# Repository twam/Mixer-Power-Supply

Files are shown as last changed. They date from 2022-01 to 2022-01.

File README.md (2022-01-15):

Mixer-Power-Supply
===

This repository is part of the USB audio mixer project described on https://www.twam.info/general/building-a-custom-usb-audio-mixer.

## License

[][cc-by-sa]

This work is licensed under a [Creative Commons Attribution-NonCommercial-ShareAlike 4.0 International License][cc-by-sa].

[][cc-by-sa]

[cc-by-sa]: http://creativecommons.org/licenses/by-nc-sa/4.0/
[cc-by-sa-image]: https://licensebuttons.net/l/by-nc-sa/4.0/88x31.png
[cc-by-sa-shield]: https://img.shields.io/badge/License-CC%20BY--NC--SA%204.0-lightgrey.svg

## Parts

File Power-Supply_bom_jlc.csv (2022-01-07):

Comment | Designator | Footprint | LCSC Part #
10u/50V | C1,C2,C3,C5,C6,C7 | C_1206_3216Metric | C13585
100nF | C4,C19,C8,C20,C21,C22,C28,C29 | C_0805_2012Metric | C49678
220u/35V | C14,C15,C16,C17 | CP_Radial_D8.0mm_P3.50mm | C201212
4u7 | C23 | C_0805_2012Metric | C1779
10p | C24 | C_0805_2012Metric | C1785
10u | C25,C26,C34 | C_0805_2012Metric | C15850
1u | C27 | C_0805_2012Metric | C28323
100nF | C30,C31,C32,C33 | C_0603_1608Metric | C14663
LL4148 | D1,D2,D3,D12 | D_MiniMELF | C9808
green | D4 | LED_0805_2012Metric | C2297
red | D5,D6,D7,D8,D9,D10,D11 | LED_0805_2012Metric | C84256
2A | F1,F2,F3 | Fuse_0603_1608Metric_Pad1.05x0.95mm_HandSolder | C187605
600R/100M | L2,L3,L5 | L_0805_2012Metric | C1017
2u2 | L4 | L_0805_2012Metric | C216156
AO3400A | Q1,Q2,Q3,Q4 | TSOT-23 | C20917
0R | R1,R15,R7,R22,R26,R31,R34 | R_0805_2012Metric | C17477
2k | R2 | R_0805_2012Metric | C17604
22k | R3 | R_0805_2012Metric | C17560
270k | R4,R17 | R_0805_2012Metric | C17589
3k3 | R5 | R_0805_2012Metric | C26010
11k | R6,R11,R18,R25,R27 | R_0805_2012Metric | C17429
39k | R9,R8,R12 | R_0805_2012Metric | C25826
4k7 | R10 | R_0805_2012Metric | C17673
68k | R13 | R_0805_2012Metric | C17801
470R | R14 | R_0805_2012Metric | C17709
10k | R16,R23,R28,R32,R33,R35,R36,R38 | R_0805_2012Metric | C17414
15k | R24 | R_0805_2012Metric | C17475
0R01 | R29 | R_1206_3216Metric | C308574
249k | R30 | R_0805_2012Metric | C25825
81R | R39 | R_0805_2012Metric | C17819
RESET | SW1 | SW_SPST_B3U-1000P | C231329
TLC5916IDR | U4 | SOIC-16_3.9x9.9mm_P1.27mm | C90107
NE5532 | U7 | SOIC-8_3.9x4.9mm_P1.27mm | C7426
TLV62569DBV | U8 | SOT-23-5 | C141836
INA138 | U9 | SOT-23-5 | C47914
MCP6002-xSN | U10 | SOIC-8_3.9x4.9mm_P1.27mm | C7377

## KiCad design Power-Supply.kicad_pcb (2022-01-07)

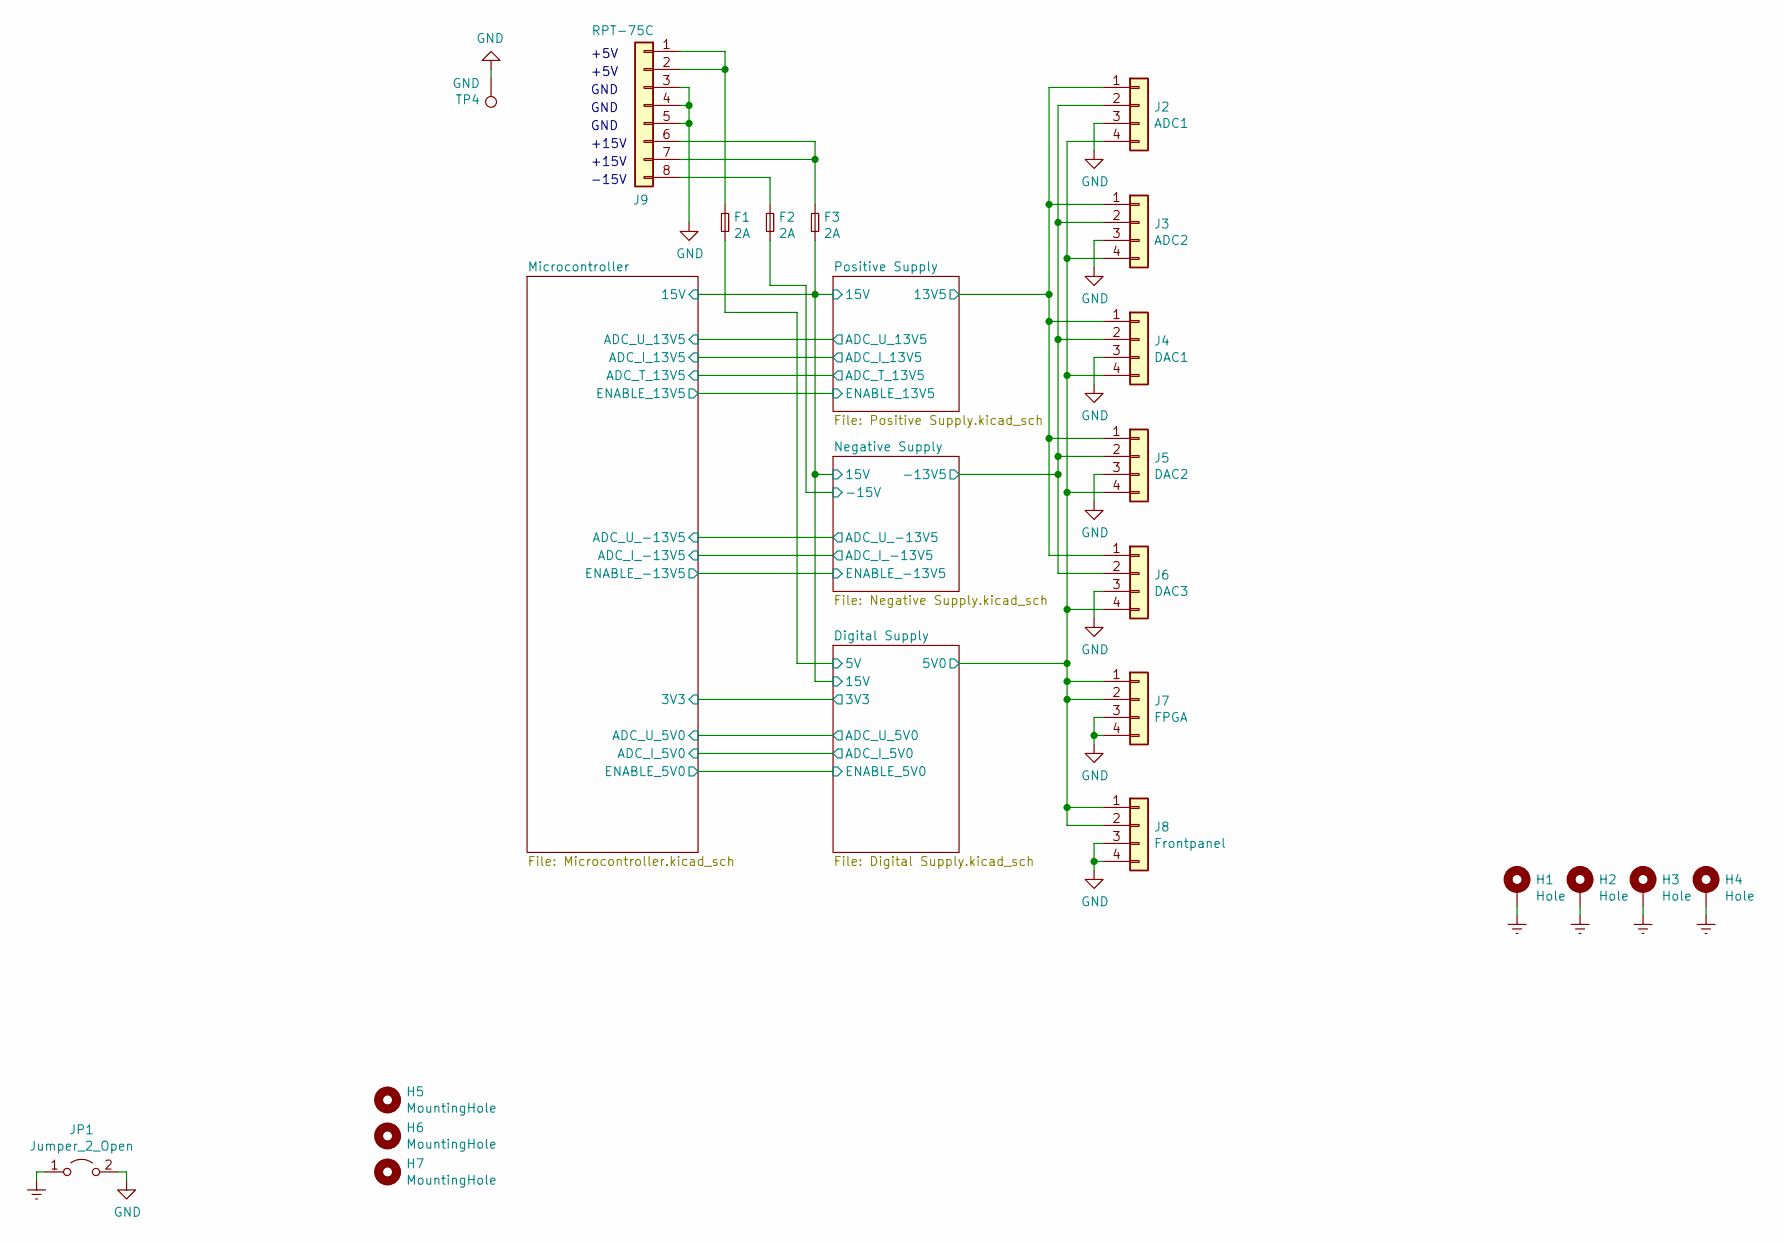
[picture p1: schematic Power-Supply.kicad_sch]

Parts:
F1, F2, F3: 2A; Fuse_0603_1608Metric_Pad1.05x0.95mm_HandSolder; LCSC C187605
H1, H2, H3, H4: Hole; MountingHole_3.2mm_M3_DIN965_Pad
H5, H6, H7: MountingHole; MountingHole_JLCPCB
J2: ADC1; JST_VH_B4P-VH_1x04_P3.96mm_Vertical
J3: ADC2; JST_VH_B4P-VH_1x04_P3.96mm_Vertical
J4: DAC1; JST_VH_B4P-VH_1x04_P3.96mm_Vertical
J5: DAC2; JST_VH_B4P-VH_1x04_P3.96mm_Vertical
J6: DAC3; JST_VH_B4P-VH_1x04_P3.96mm_Vertical
J7: FPGA; JST_VH_B4P-VH_1x04_P3.96mm_Vertical
J8: Frontpanel; JST_VH_B4P-VH_1x04_P3.96mm_Vertical
J9: RPT-75C; JST_VH_B8P-VH_1x08_P3.96mm_Vertical
JP1: Jumper_2_Open; SolderJumper-2_P1.3mm_Open_RoundedPad1.0x1.5mm
TP4: GND; TestPoint_Pad_D2.0mm

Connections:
/Digital Supply/5V: F1.1; also elsewhere on the board
/Digital Supply/5V0: J2.4, J3.4, J4.4, J5.4, J6.4, J7.1, J7.2, J8.1, J8.2; also elsewhere on the board
/Digital Supply/15V: F3.1; also elsewhere on the board
/Negative Supply/-13V5: J2.2, J3.2, J4.2, J5.2, J6.2; also elsewhere on the board
/Negative Supply/-15V: F2.1; also elsewhere on the board
/Positive Supply/13V5: J2.1, J3.1, J4.1, J5.1, J6.1; also elsewhere on the board
Earth: H1.1, H2.1, H3.1, H4.1, JP1.1 (A)
GND: J2.3, J3.3, J4.3, J5.3, J6.3, J7.3, J7.4, J8.3, J8.4, J9.3, J9.4, J9.5, JP1.2 (B), TP4.1; also elsewhere on the board
unnamed: F1.2, J9.1, J9.2
unnamed: F2.2, J9.8
unnamed: F3.2, J9.6, J9.7

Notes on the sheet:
+5V
GND
-15V
+15V

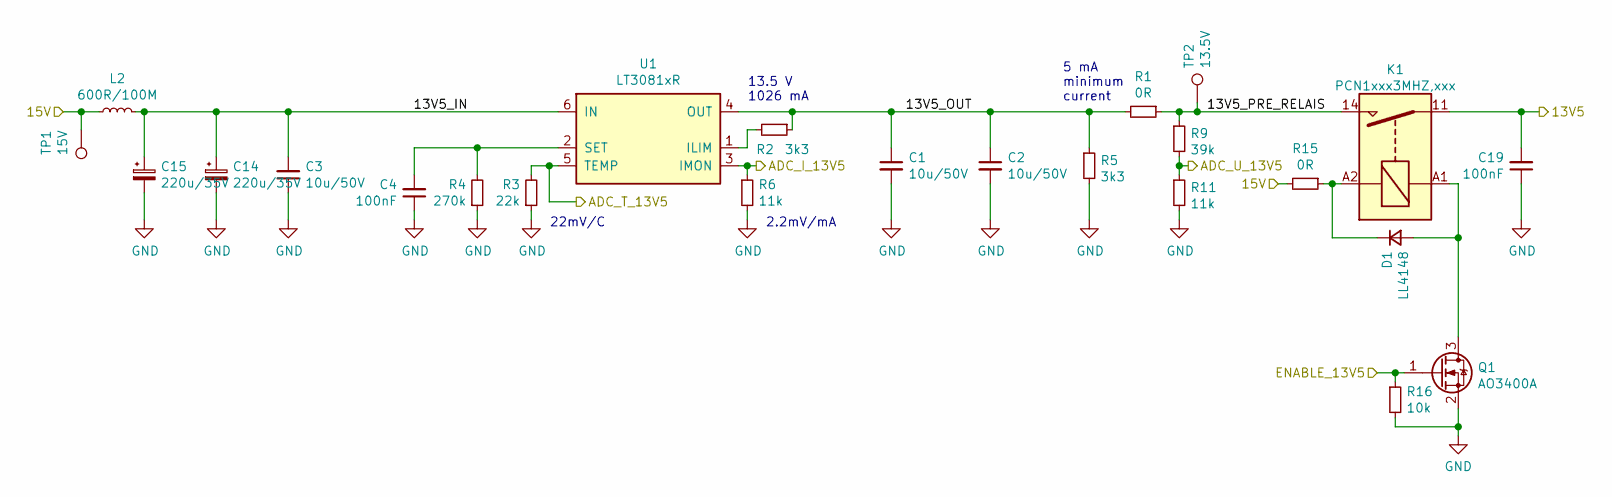
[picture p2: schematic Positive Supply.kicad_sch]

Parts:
C1, C2, C3: 10u/50V; C_1206_3216Metric; LCSC C13585
C4, C19: 100nF; C_0805_2012Metric; LCSC C49678
C14, C15: 220u/35V; CP_Radial_D8.0mm_P3.50mm; LCSC C201212
D1: LL4148; D_MiniMELF; LCSC C9808
K1: PCN1xxx3MHZ,xxx
L2: 600R/100M; L_0805_2012Metric; LCSC C1017
Q1: AO3400A; TSOT-23; LCSC C20917
R1, R15: 0R; R_0805_2012Metric; LCSC C17477
R2, R5: 3k3; R_0805_2012Metric; LCSC C26010
R3: 22k; R_0805_2012Metric; LCSC C17560
R4: 270k; R_0805_2012Metric; LCSC C17589
R6, R11: 11k; R_0805_2012Metric; LCSC C17429
R9: 39k; R_0805_2012Metric; LCSC C25826
R16: 10k; R_0805_2012Metric; LCSC C17414
TP1: 15V; TestPoint_Pad_D2.0mm
TP2: 13.5V; TestPoint_Pad_D2.0mm
U1: LT3081xR; TO-220-7_P2.54x3.8mm_StaggerOdd_Lead5.85mm_TabDown

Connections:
/Digital Supply/15V: L2.1, R15.2, TP1.1; also elsewhere on the board
/Microcontroller/ADC_I_13V5: R6.1, U1.3 (IMON); also elsewhere on the board
/Microcontroller/ADC_T_13V5: R3.2, U1.5 (TEMP); also elsewhere on the board
/Microcontroller/ADC_U_13V5: R9.2, R11.1; also elsewhere on the board
/Microcontroller/ENABLE_13V5: Q1.1 (G), R16.1; also elsewhere on the board
/Positive Supply/13V5: C19.2, K1.11; also elsewhere on the board
/Positive Supply/13V5_IN: C3.2, C14.1, C15.1, L2.2, U1.6 (IN)
/Positive Supply/13V5_OUT: C1.1, C2.1, R1.2, R2.1, R5.1, U1.4 (OUT)
/Positive Supply/13V5_PRE_RELAIS: K1.14, R1.1, R9.1, TP2.1
GND: C1.2, C2.2, C3.1, C4.1, C14.2, C15.2, C19.1, Q1.2 (S), R3.1, R4.1, R5.2, R6.2, R11.2, R16.2; also elsewhere on the board
unnamed: C4.2, R4.2, U1.2 (SET)
unnamed: D1.1 (K), K1.A2, R15.1
unnamed: D1.2 (A), K1.A1, Q1.3 (D)
unnamed: R2.2, U1.1 (ILIM)

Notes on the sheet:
2.2mV/mA
5 mA minimum current
22mV/C
13.5 V 1026 mA

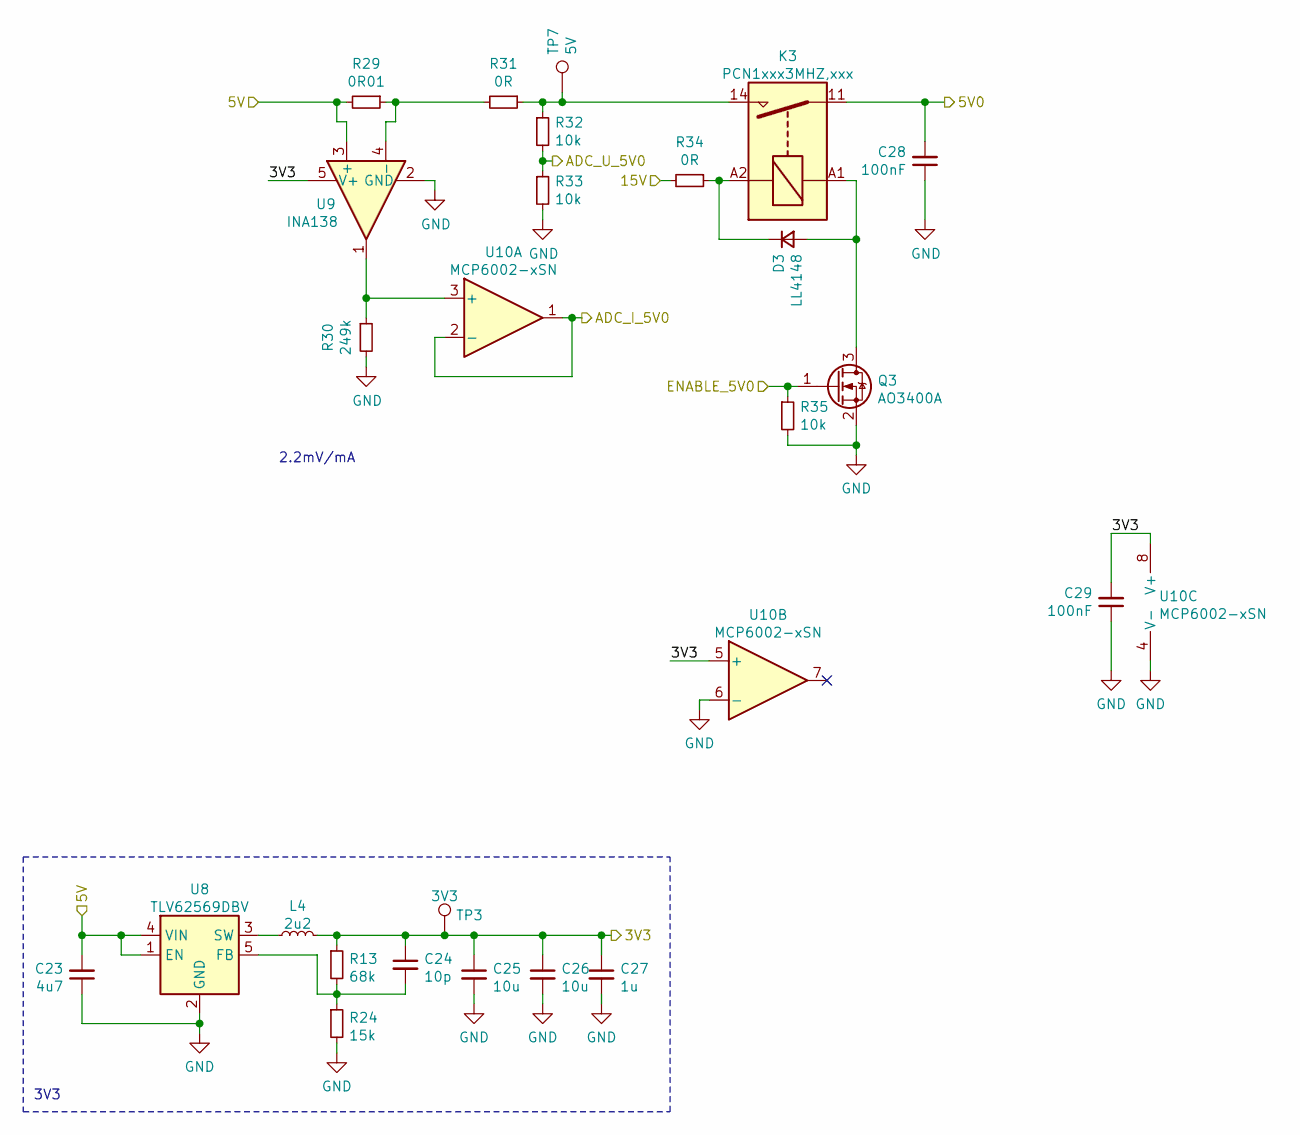
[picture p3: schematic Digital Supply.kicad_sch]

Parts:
C23: 4u7; C_0805_2012Metric; LCSC C1779
C24: 10p; C_0805_2012Metric; LCSC C1785
C25, C26: 10u; C_0805_2012Metric; LCSC C15850
C27: 1u; C_0805_2012Metric; LCSC C28323
C28, C29: 100nF; C_0805_2012Metric; LCSC C49678
D3: LL4148; D_MiniMELF; LCSC C9808
K3: PCN1xxx3MHZ,xxx
L4: 2u2; L_0805_2012Metric; LCSC C216156
Q3: AO3400A; TSOT-23; LCSC C20917
R13: 68k; R_0805_2012Metric; LCSC C17801
R24: 15k; R_0805_2012Metric; LCSC C17475
R29: 0R01; R_1206_3216Metric; LCSC C308574
R30: 249k; R_0805_2012Metric; LCSC C25825
R31, R34: 0R; R_0805_2012Metric; LCSC C17477
R32, R33, R35: 10k; R_0805_2012Metric; LCSC C17414
TP3: 3V3; TestPoint_Pad_D1.5mm
TP7: 5V; TestPoint_Pad_D2.0mm
U8: TLV62569DBV; SOT-23-5; LCSC C141836
U9: INA138; SOT-23-5; LCSC C47914
U10: MCP6002-xSN; SOIC-8_3.9x4.9mm_P1.27mm

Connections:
/Digital Supply/3V3: C24.1, C25.1, C26.1, C27.1, C29.2, L4.2, R13.1, TP3.1, U9.5 (V+), U10.5 (+), U10.8 (V+); also elsewhere on the board
/Digital Supply/5V: C23.2, R29.2, U8.1 (EN), U8.4 (VIN), U9.3 (+); also elsewhere on the board
/Digital Supply/5V0: C28.2, K3.11; also elsewhere on the board
/Digital Supply/15V: R34.2; also elsewhere on the board
/Digital Supply/ADC_I_5V0: U10.1, U10.2 (-); also elsewhere on the board
/Digital Supply/ADC_U_5V0: R32.2, R33.1; also elsewhere on the board
/Digital Supply/ENABLE_5V0: Q3.1 (G), R35.1; also elsewhere on the board
GND: C23.1, C25.2, C26.2, C27.2, C28.1, C29.1, Q3.2 (S), R24.2, R30.2, R33.2, R35.2, U8.2 (GND), U9.2 (GND), U10.4 (V-), U10.6 (-); also elsewhere on the board
unnamed: C24.2, R13.2, R24.1, U8.5 (FB)
unnamed: D3.1 (K), K3.A2, R34.1
unnamed: D3.2 (A), K3.A1, Q3.3 (D)
unnamed: K3.14, R31.1, R32.1, TP7.1
unnamed: L4.1, U8.3 (SW)
unnamed: R29.1, R31.2, U9.4 (-)
unnamed: R30.1, U9.1, U10.3 (+)

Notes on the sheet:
2.2mV/mA
3V3

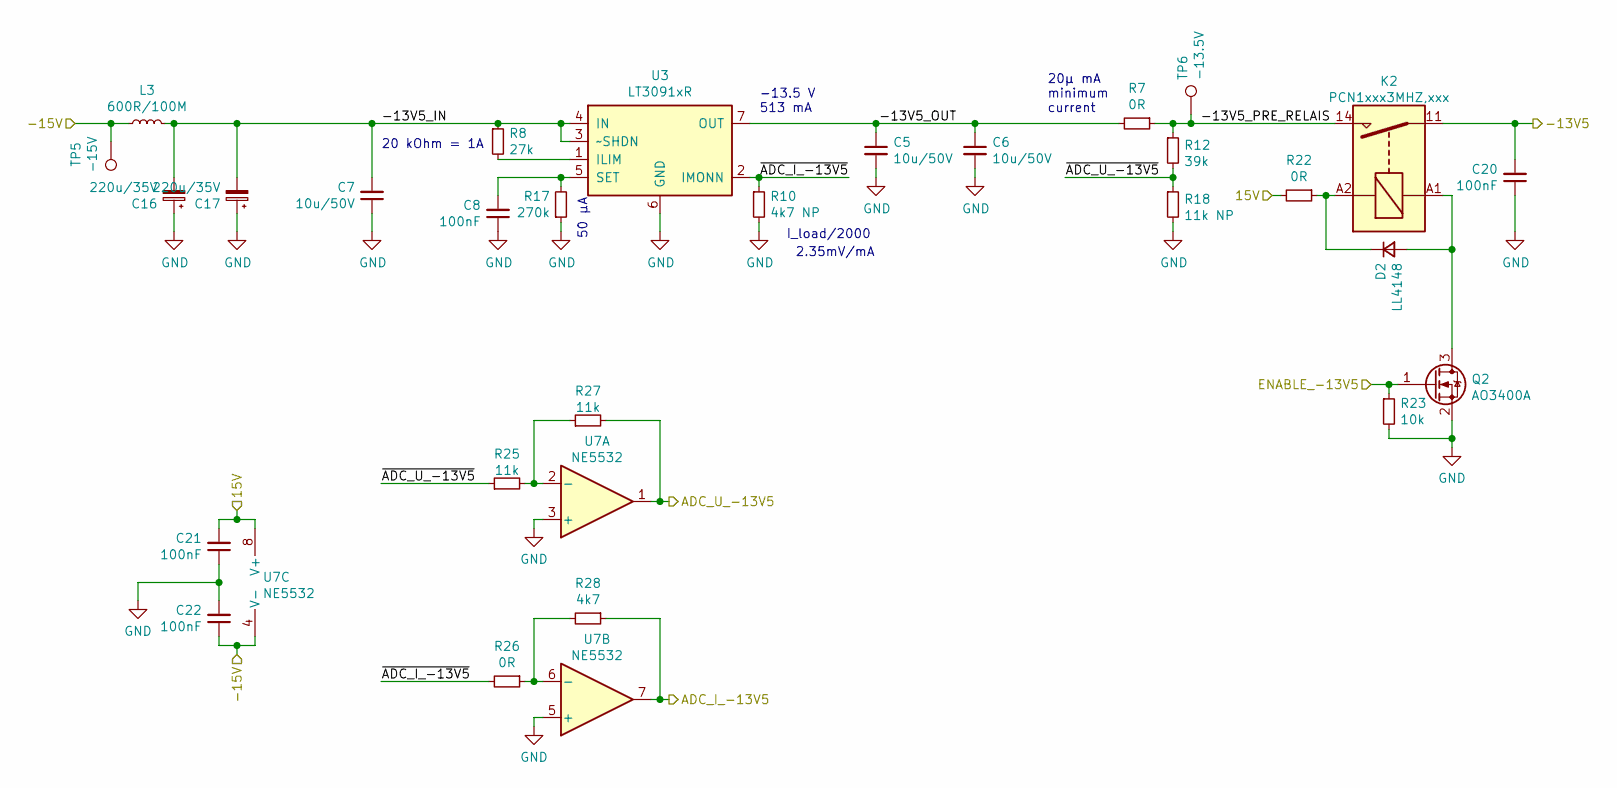
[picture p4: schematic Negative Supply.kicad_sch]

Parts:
C5, C6, C7: 10u/50V; C_1206_3216Metric; LCSC C13585
C8, C20, C21, C22: 100nF; C_0805_2012Metric; LCSC C49678
C16, C17: 220u/35V; CP_Radial_D8.0mm_P3.50mm; LCSC C201212
D2: LL4148; D_MiniMELF; LCSC C9808
K2: PCN1xxx3MHZ,xxx
L3: 600R/100M; L_0805_2012Metric; LCSC C1017
Q2: AO3400A; TSOT-23; LCSC C20917
R7, R22, R26: 0R; R_0805_2012Metric; LCSC C17477
R8: 27k; R_0805_2012Metric; LCSC C26010
R10: 4k7 NP; R_0805_2012Metric; LCSC C17673
R12: 39k; R_0805_2012Metric; LCSC C25826
R17: 270k; R_0805_2012Metric; LCSC C17589
R18: 11k NP; R_0805_2012Metric
R23: 10k; R_0805_2012Metric; LCSC C17414
R25, R27: 11k; R_0805_2012Metric; LCSC C17429
R28: 4k7; R_0805_2012Metric; LCSC C17673
TP5: -15V; TestPoint_Pad_D2.0mm
TP6: -13.5V; TestPoint_Pad_D2.0mm
U3: LT3091xR; TO-220-7_P2.54x3.8mm_StaggerOdd_Lead5.85mm_TabDown
U7: NE5532; SOIC-8_3.9x4.9mm_P1.27mm

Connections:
/Digital Supply/15V: C21.2, R22.2, U7.8 (V+); also elsewhere on the board
/Microcontroller/ADC_I_-13V5: R28.1, U7.7; also elsewhere on the board
/Microcontroller/ADC_U_-13V5: R27.2, U7.1; also elsewhere on the board
/Microcontroller/ENABLE_-13V5: Q2.1 (G), R23.1; also elsewhere on the board
/Negative Supply/-13V5: C20.2, K2.11; also elsewhere on the board
/Negative Supply/-13V5_IN: C7.2, C16.2, C17.2, L3.2, R8.1, U3.3 (~SHDN), U3.4 (IN)
/Negative Supply/-13V5_OUT: C5.1, C6.1, R7.2, U3.7 (OUT)
/Negative Supply/-13V5_PRE_RELAIS: K2.14, R7.1, R12.1, TP6.1
/Negative Supply/-15V: C22.1, L3.1, TP5.1, U7.4 (V-); also elsewhere on the board
/Negative Supply/~ADC_I_-13V5: R10.1, R26.2, U3.2 (IMONN)
/Negative Supply/~ADC_U_-13V5: R12.2, R18.1, R25.1
GND: C5.2, C6.2, C7.1, C8.1, C16.1, C17.1, C20.1, C21.1, C22.2, Q2.2 (S), R10.2, R17.1, R18.2, R23.2, U3.6 (GND), U7.3 (+), U7.5 (+); also elsewhere on the board
unnamed: C8.2, R17.2, U3.5 (SET)
unnamed: D2.1 (K), K2.A2, R22.1
unnamed: D2.2 (A), K2.A1, Q2.3 (D)
unnamed: R8.2, U3.1 (ILIM)
unnamed: R25.2, R27.1, U7.2 (-)
unnamed: R26.1, R28.2, U7.6 (-)

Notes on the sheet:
20µ mA minimum current
20 kOhm = 1A
I_load/2000
50 µA
2.35mV/mA
-13.5 V 513 mA

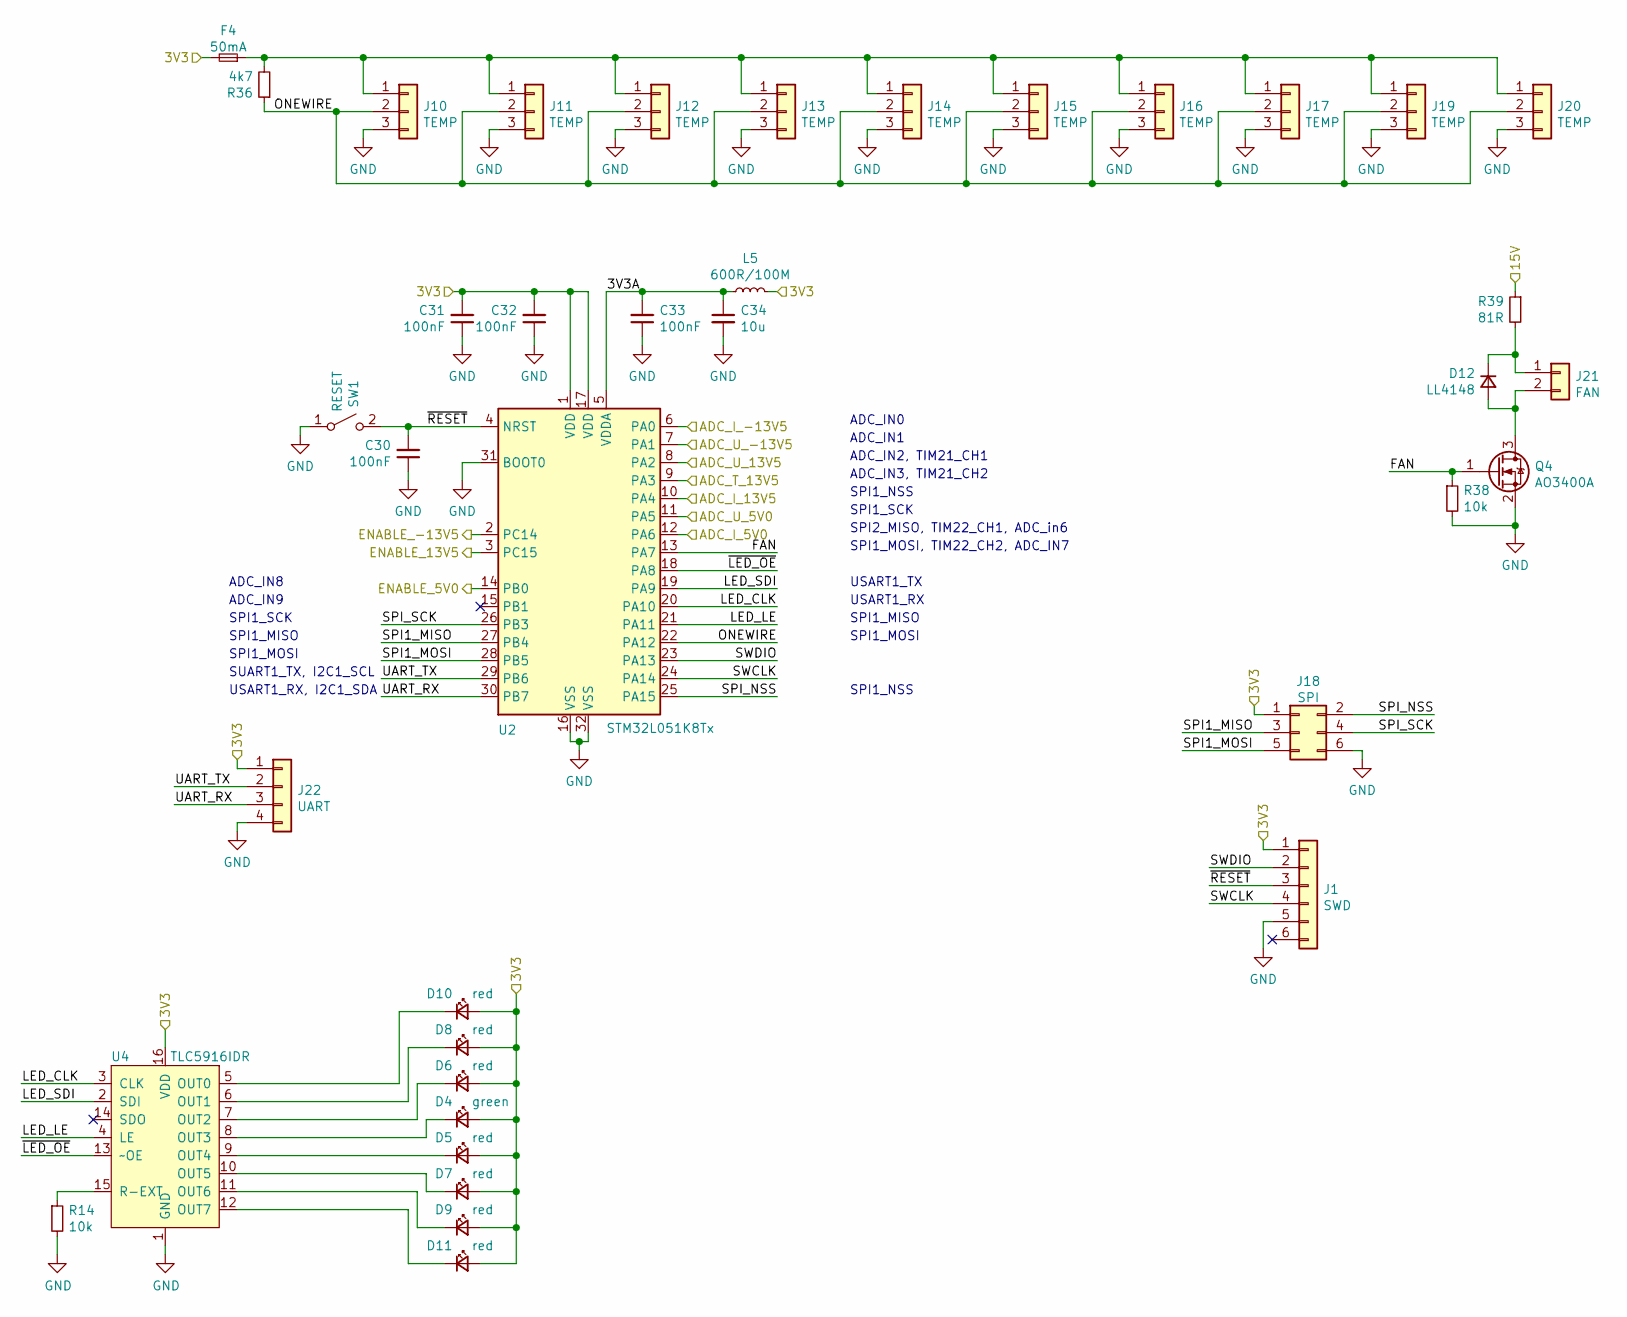
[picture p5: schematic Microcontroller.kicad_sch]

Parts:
C30, C31, C32, C33: 100nF; C_0603_1608Metric; LCSC C14663
C34: 10u; C_0805_2012Metric; LCSC C15850
D4: green; LED_0805_2012Metric; LCSC C2297
D5, D6, D7, D8, D9, D10, D11: red; LED_0805_2012Metric; LCSC C84256
D12: LL4148; D_MiniMELF; LCSC C9808
F4: 50mA; Fuse_0603_1608Metric_Pad1.05x0.95mm_HandSolder
J1: SWD; Tag-Connect_TC2030-IDC-NL_2x03_P1.27mm_Vertical
J10, J11, J12, J13, J14, J15, J16, J17, J19, J20: TEMP; Molex_KK-254_AE-6410-03A_1x03_P2.54mm_Vertical
J18: SPI; PinHeader_2x03_P2.54mm_Vertical
J21: FAN; Molex_KK-254_AE-6410-02A_1x02_P2.54mm_Vertical
J22: UART; PinHeader_1x04_P2.54mm_Vertical
L5: 600R/100M; L_0805_2012Metric; LCSC C1017
Q4: AO3400A; TSOT-23; LCSC C20917
R14, R38: 10k; R_0805_2012Metric; LCSC C17414
R36: 4k7; R_0805_2012Metric; LCSC C17673
R39: 81R; R_0805_2012Metric; LCSC C17819
SW1: RESET; SW_SPST_B3U-1000P; LCSC C231329
U2: STM32L051K8Tx; LQFP-32_7x7mm_P0.8mm
U4: TLC5916IDR; SOIC-16_3.9x9.9mm_P1.27mm; LCSC C90107

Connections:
/Digital Supply/3V3: C31.2, C32.2, D4.2 (A), D5.2 (A), D6.2 (A), D7.2 (A), D8.2 (A), D9.2 (A), D10.2 (A), D11.2 (A), F4.2, J1.1, J18.1, J22.1, L5.2, U2.1 (VDD), U2.17 (VDD), U4.16 (VDD); also elsewhere on the board
/Digital Supply/15V: R39.1; also elsewhere on the board
/Digital Supply/ADC_I_5V0: U2.12 (PA6); also elsewhere on the board
/Digital Supply/ADC_U_5V0: U2.11 (PA5); also elsewhere on the board
/Digital Supply/ENABLE_5V0: U2.14 (PB0); also elsewhere on the board
/Microcontroller/3V3A: C33.2, C34.1, L5.1, U2.5 (VDDA)
/Microcontroller/ADC_I_13V5: U2.10 (PA4); also elsewhere on the board
/Microcontroller/ADC_I_-13V5: U2.6 (PA0); also elsewhere on the board
/Microcontroller/ADC_T_13V5: U2.9 (PA3); also elsewhere on the board
/Microcontroller/ADC_U_13V5: U2.8 (PA2); also elsewhere on the board
/Microcontroller/ADC_U_-13V5: U2.7 (PA1); also elsewhere on the board
/Microcontroller/ENABLE_13V5: U2.3 (PC15); also elsewhere on the board
/Microcontroller/ENABLE_-13V5: U2.2 (PC14); also elsewhere on the board
/Microcontroller/FAN: Q4.1 (G), R38.1, U2.13 (PA7)
/Microcontroller/LED_CLK: U2.20 (PA10), U4.3 (CLK)
/Microcontroller/LED_LE: U2.21 (PA11), U4.4 (LE)
/Microcontroller/LED_SDI: U2.19 (PA9), U4.2 (SDI)
/Microcontroller/ONEWIRE: J10.2, J11.2, J12.2, J13.2, J14.2, J15.2, J16.2, J17.2, J19.2, J20.2, R36.1, U2.22 (PA12)
/Microcontroller/SPI1_MISO: J18.3, U2.27 (PB4)
/Microcontroller/SPI1_MOSI: J18.5, U2.28 (PB5)
/Microcontroller/SPI_NSS: J18.2, U2.25 (PA15)
/Microcontroller/SPI_SCK: J18.4, U2.26 (PB3)
/Microcontroller/SWCLK: J1.4, U2.24 (PA14)
/Microcontroller/SWDIO: J1.2, U2.23 (PA13)
/Microcontroller/UART_RX: J22.3, U2.30 (PB7)
/Microcontroller/UART_TX: J22.2, U2.29 (PB6)
/Microcontroller/~LED_OE: U2.18 (PA8), U4.13 (~OE)
/Microcontroller/~RESET: C30.2, J1.3, SW1.2 (B), U2.4 (NRST)
GND: C30.1, C31.1, C32.1, C33.1, C34.2, J1.5, J10.3, J11.3, J12.3, J13.3, J14.3, J15.3, J16.3, J17.3, J18.6, J19.3, J20.3, J22.4, Q4.2 (S), R14.2, R38.2, SW1.1 (A), U2.16 (VSS), U2.31 (BOOT0), U2.32 (VSS), U4.1 (GND); also elsewhere on the board
unnamed: D4.1 (K), U4.8 (OUT3)
unnamed: D5.1 (K), U4.9 (OUT4)
unnamed: D6.1 (K), U4.7 (OUT2)
unnamed: D7.1 (K), U4.10 (OUT5)
unnamed: D8.1 (K), U4.6 (OUT1)
unnamed: D9.1 (K), U4.11 (OUT6)
unnamed: D10.1 (K), U4.5 (OUT0)
unnamed: D11.1 (K), U4.12 (OUT7)
unnamed: D12.1 (K), J21.1, R39.2
unnamed: D12.2 (A), J21.2, Q4.3 (D)
unnamed: F4.1, J10.1, J11.1, J12.1, J13.1, J14.1, J15.1, J16.1, J17.1, J19.1, J20.1, R36.2
unnamed: R14.1, U4.15 (R-EXT)

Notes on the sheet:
USART1_RX, I2C1_SDA
SPI1_MISO
SPI1_SCK
SPI1_MOSI
SPI1_MISO
SPI1_NSS
USART1_RX
SPI2_MISO, TIM22_CH1, ADC_in6
ADC_IN3, TIM21_CH2
SPI1_MOSI, TIM22_CH2, ADC_IN7
ADC_IN0
SUART1_TX, I2C1_SCL
ADC_IN9
ADC_IN8
ADC_IN2, TIM21_CH1
USART1_TX
ADC_IN1

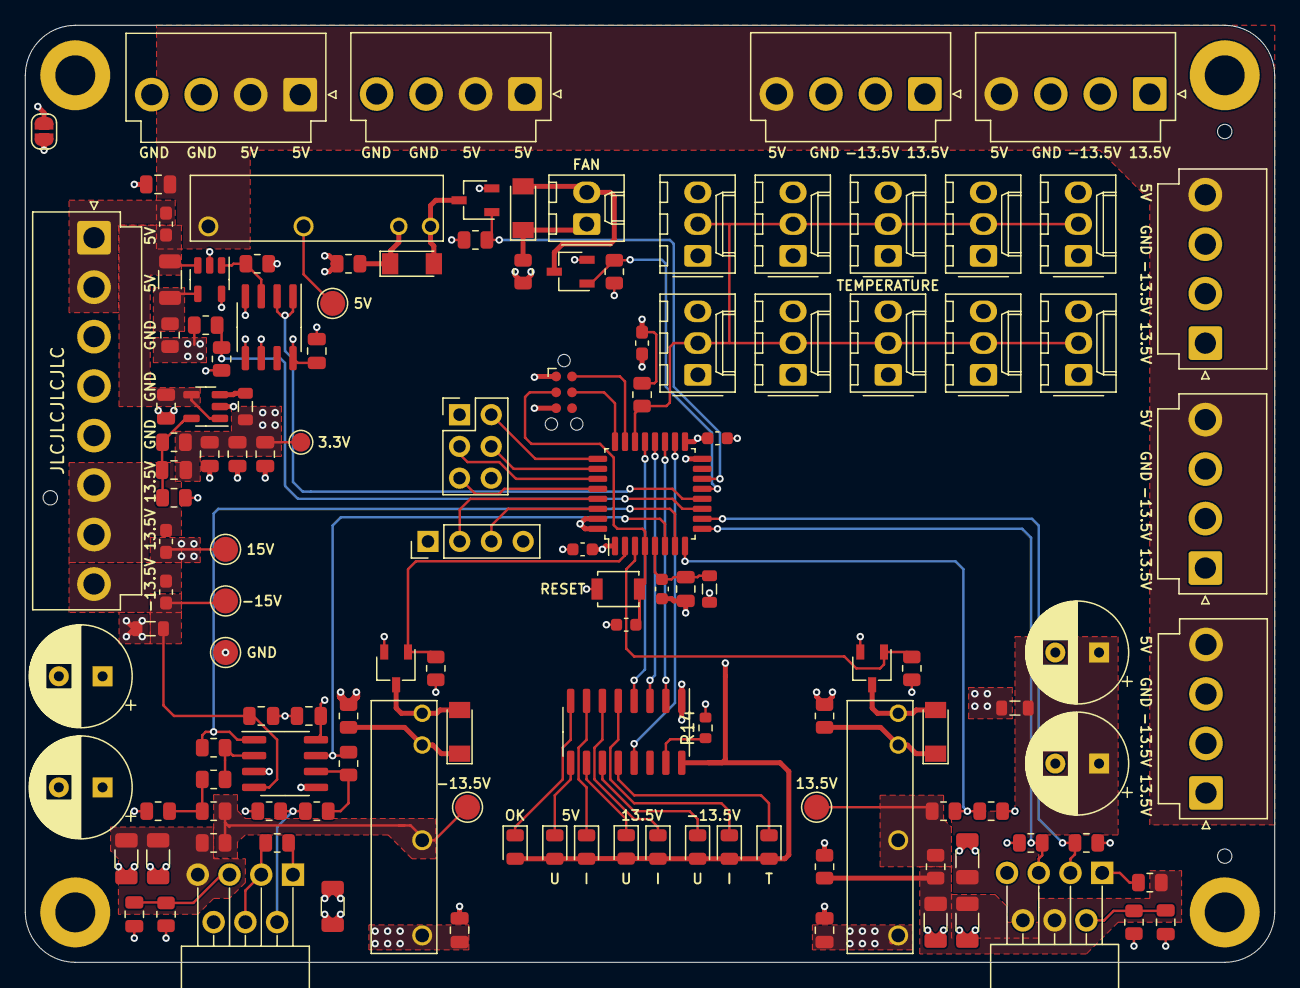
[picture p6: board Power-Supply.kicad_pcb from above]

Board: 4 copper layers, 100.0 x 75.0 mm, 136 parts (0 on the bottom side), 75 nets.

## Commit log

2021-06-05 Initial commit. Rev 2
    [Power-Supply-B_Cu.gbr, Power-Supply-B_Mask.gbr, Power-Supply-B_Paste.gbr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]
2022-01-07 Update Gerbers and add JLCPCB position/BOM files
    [Power-Supply-B_Cu.gbr, Power-Supply-B_Mask.gbr, Power-Supply-B_Paste.gbr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]
2022-01-07 Update to KiCad 6
    [Digital Supply.kicad_sch, Microcontroller.kicad_sch, Negative Supply.kicad_sch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]
